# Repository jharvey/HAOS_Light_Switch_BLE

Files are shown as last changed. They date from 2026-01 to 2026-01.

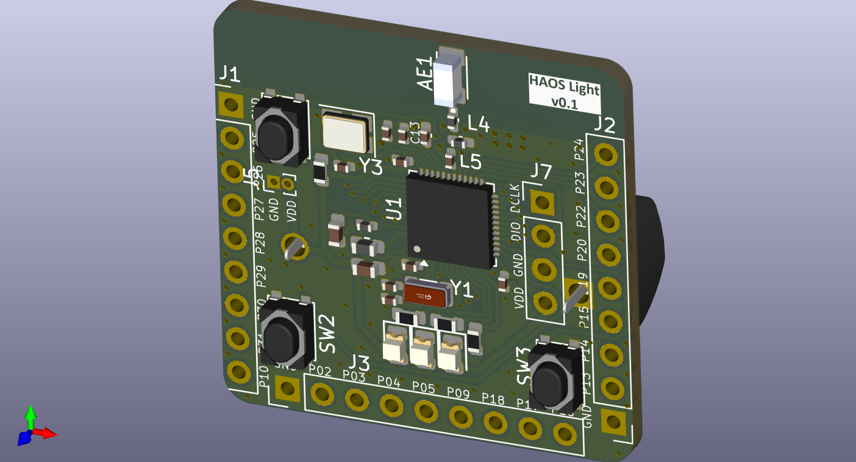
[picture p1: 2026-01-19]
pcb/HAOS_Light_Switch_BLE_KiCAD-9/jlcpcb/V0.1/HAOS_Light_Switch_BLE_ISO-front.png

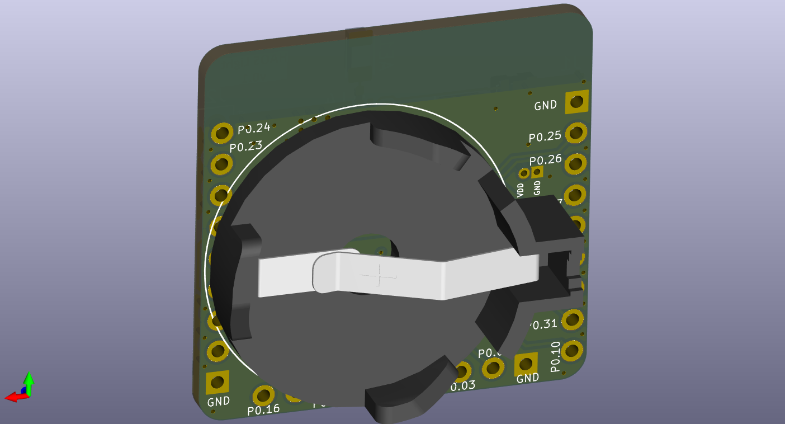
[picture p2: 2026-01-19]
pcb/HAOS_Light_Switch_BLE_KiCAD-9/jlcpcb/V0.1/HAOS_Light_Switch_BLE_ISO-back.png

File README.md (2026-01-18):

## Overview 

**Reference Designs** based on 
- Mohamed-U3 PCB V3.1 of hackaBLE https://github.com/Mohamed-U3/ElectronutLabs-hackaBLE
- Reference code https://github.com/agittins/NarfButt\
- uses https://github.com/bouni/kicad-jlcpcb-tools for JLCPCB intergration.
- uses https://raw.githubusercontent.com/CDFER/

**Features**

- Raytac MDBT42 based on Nordic Semiconductor's nRF52832 SOC with chip antenna
- 3 LED's
- Button user configurable, set as RESET by default
- SWD programming headers
- CR2032 power
- Button up
- Button down

**nRF52 IO**
- P0.00 32.768KHz with 12pF load caps
- P0.01 32.768KHz with 12pF load caps
- P0.11 Up push button
- P0.12 Down push button
- P0.17 Red LED via 33 ohm pull up at about 5ma when on. 
- P0.18 Green LED via 10 ohm pull up at about 5ma when on. 
- P0.19 White LED via 10 ohm pull up at about 5ma when on. 
- P0.21 Reset push button via 10k pull up resistor. 
- Ant 0.8pF and 3.9nH filter to PCB trace antenna. 
- XC1 ABM8-32.000MHZ-B2-T3 with 12pF load caps
- XC2 ABM8-32.000MHZ-B2-T3 with 12pF load caps
- VDD 4.7uF, 0.1uF, 0.1uF caps to gnd
- DEC1 0.1uF to Ggnd
- DEC2 No connection
- DEC3 No connection
- DEC4 to DCC via inductors listed below. 
- DCC 10uH to 15nH to DEC4 to 1uF to gnd
- SWD is connected to a dedicated connector with VDD and gnd
- All unused pins are routed to a connector which allows probing with a scope or adding prototype features.

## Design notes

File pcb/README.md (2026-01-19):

# HAOS_Light_Switch_BLE
A compact Nordic nRF52832 BLE module for HAOS light switch signals.

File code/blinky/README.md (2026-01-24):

## 1. Brief Overview
This is a baby step for making a BLE switch for HAOS. This is intended to simply blink an LED showing that you have suscessfully programmed the device. It's a hello world / baby step applicaion. 

## 2. Installation & VS Code Setup
To compile and flash this project, your development environment must be configured for **nRF Connect SDK (NCS) v3.x.x (2026)**.

### Software Prerequisites
1.  **nRF Connect Desktop:** Install the [nRF Connect Desktop tool](https://www.nordicsemi.com).
2.  **Toolchain:** Use the **Toolchain Manager** within nRF Connect Desktop to install **SDK v3.2.1** (or the latest stable 2026 release).
3.  **VS Code Extensions:**
    *   **nRF Connect for VS Code Extension Pack** (Essential).
    *   **C/C++ Extension** (by Microsoft).

### Building the Project
1.  Open the `code/HAOS_Button` folder in VS Code.
2.  In the nRF Connect Sidebar, click **Add Build Configuration**.
3.  **Board Target:** Select `nrf52dk/nrf52832`.
4.  **Configuration:** Ensure `prj.conf` is selected.
5.  Click **Build Configuration**. 
    *   *Note: Use **Pristine Build** (Refresh icon) if you modify `app.overlay` or `prj.conf`.*

## 3. Hardware Specifications & Key Assumptions
This project is mapped to the custom HAOS PCB layout.

### GPIO Mapping
The hardware utilizes the following pinout as defined in the `app.overlay`:

| Component | GPIO Pin | Logic | Description |
| :--- | :--- | :--- | :--- |
| **Red LED** | `P0.06` | Active Low | Status/Error Indicator |
| **White LED** | `P0.07` | Active Low | Secondary Indicator |
| **Green LED** | `P0.08` | Active Low | Success/Heartbeat Indicator |
| **Up Button** | `P0.11` | Pull-Up | Shorts to GND when pressed |
| **Down Button** | `P0.12` | Pull-Up | Shorts to GND when pressed |
| **Reset/Button**| `P0.21` | Pull-Up | Hardware Reset / Input |

### Oscillator & Crystal Frequencies
To maintain BLE timing accuracy and achieve micro-ampere sleep currents, the following crystal assumptions are made:
*   **High-Frequency Clock (HFCLK):** 32 MHz Crystal (Required for BLE radio operation).
*   **Low-Frequency Clock (LFCLK):** 32.768 kHz Crystal (Required for accurate sleep-interval timing).
*   **DCDC Converter:** Enabled in `prj.conf` to reduce peak current draw from the CR2032 during radio bursts.

### Programming Interface (J6 Header)
*   **Connector:** Tag-Connect TC2030-IDC-NL (6-pin).
*   **Programmer:** SEGGER J-Link (e.g., EDU Mini).
*   **Power Note:** The programmer does **not** provide power via the J6 header. The board must be powered by the CR2032 or an external 3V supply during flashing.

## 4. Debugging & Output
Debugging is handled via **SWO (Single Wire Output)** on the J6 header to avoid the power overhead of a traditional UART.
*   **Frequency:** 2,000,000 Hz.
*   **Tools:** View logs using the **SEGGER J-Link SWO Viewer**.

### Notes
2026-01-24 As of this date, the baord has not be manufactured or tested. This is still a draft version.

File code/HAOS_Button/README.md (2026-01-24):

# HAOS Button: Ultra-Low Power BLE Light Switch

An ultra-low-power, CR2032-battery-operated Bluetooth Low Energy (BLE) light switch designed specifically for **Home Assistant**. This project utilizes the **BTHome V2** protocol to provide long battery life and "no-pairing" automatic discovery.

## 1. Brief Overview
The HAOS Button is a custom-engineered remote for Home Assistant. Instead of maintaining a power-hungry active connection, it utilizes BLE Advertising to broadcast state changes.
*   **Hardware:** nRF52832 SoC.
*   **Power:** Powered by a single **CR2032 coin cell**.
*   **Protocol:** BTHome V2 (non-encrypted) for instant integration with HAOS.
*   **Form Factor:** Designed to fit behind existing wall plates or as a standalone remote. Small enough to be on a key chain. 

## 2. Installation & VS Code Setup
To compile and flash this project, your development environment must be configured for **nRF Connect SDK (NCS) v3.x.x (2026)**.

### Software Prerequisites
1.  **nRF Connect Desktop:** Install the [nRF Connect Desktop tool](https://www.nordicsemi.com).
2.  **Toolchain:** Use the **Toolchain Manager** within nRF Connect Desktop to install **SDK v3.2.1** (or the latest stable 2026 release).
3.  **VS Code Extensions:**
    *   **nRF Connect for VS Code Extension Pack** (Essential).
    *   **C/C++ Extension** (by Microsoft).

### Building the Project
1.  Open the `code/HAOS_Button` folder in VS Code.
2.  In the nRF Connect Sidebar, click **Add Build Configuration**.
3.  **Board Target:** Select `nrf52dk/nrf52832`.
4.  **Configuration:** Ensure `prj.conf` is selected.
5.  Click **Build Configuration**. 
    *   *Note: Use **Pristine Build** (Refresh icon) if you modify `app.overlay` or `prj.conf`.*

## 3. Hardware Specifications & Key Assumptions
This project is mapped to the custom HAOS PCB layout.

### GPIO Mapping
The hardware utilizes the following pinout as defined in the `app.overlay`:

| Component | GPIO Pin | Logic | Description |
| :--- | :--- | :--- | :--- |
| **Red LED** | `P0.06` | Active Low | Status/Error Indicator |
| **White LED** | `P0.07` | Active Low | Secondary Indicator |
| **Green LED** | `P0.08` | Active Low | Success/Heartbeat Indicator |
| **Up Button** | `P0.11` | Pull-Up | Shorts to GND when pressed |
| **Down Button** | `P0.12` | Pull-Up | Shorts to GND when pressed |
| **Reset/Button**| `P0.21` | Pull-Up | Hardware Reset / Input |

### Oscillator & Crystal Frequencies
To maintain BLE timing accuracy and achieve micro-ampere sleep currents, the following crystal assumptions are made:
*   **High-Frequency Clock (HFCLK):** 32 MHz Crystal (Required for BLE radio operation).
*   **Low-Frequency Clock (LFCLK):** 32.768 kHz Crystal (Required for accurate sleep-interval timing).
*   **DCDC Converter:** Enabled in `prj.conf` to reduce peak current draw from the CR2032 during radio bursts.

### Programming Interface (J6 Header)
*   **Connector:** Tag-Connect TC2030-IDC-NL (6-pin).
*   **Programmer:** SEGGER J-Link (e.g., EDU Mini).
*   **Power Note:** The programmer does **not** provide power via the J6 header. The board must be powered by the CR2032 or an external 3V supply during flashing.

## 4. Debugging & Output
Debugging is handled via **SWO (Single Wire Output)** on the J6 header to avoid the power overhead of a traditional UART.
*   **Frequency:** 2,000,000 Hz.
*   **Tools:** View logs using the **SEGGER J-Link SWO Viewer**.

## 5. Home Assistant Integration
1.  Navigate to **Settings > Devices & Services** in your HAOS instance.
2.  Press any button on the device to begin advertising.
3.  Home Assistant will automatically discover the device as a **BTHome** integration.
4.  Once configured, buttons will appear as event entities for use in Automations.

### Notes
2026-01-24 As of this date, the baord has not be manufactured or tested. This is still a draft version.

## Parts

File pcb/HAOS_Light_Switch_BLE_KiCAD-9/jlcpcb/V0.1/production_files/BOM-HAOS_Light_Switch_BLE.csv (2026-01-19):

Comment | Designator | Footprint | LCSC | Quantity
100nF | C11,C7,C9 | C_0402 | C307331 | 3
100pF | C12 | C_0402 | C1546 | 1
10kΩ | R1 | R_0603 | C25804 | 1
10uH,3mA | L2 | L_0603 | C1035 | 1
10Ω | R2,R3 | R_0603 | C22859 | 2
12pF | C1,C2,C5,C6 | C_0402 | C1547 | 4
15nH,300mA | L1 | L_0402 | C27143 | 1
1pF | C3 | C_0402 | C1550 | 1
1uF | C10 | C_0603 | C15849 | 1
2.7uH | L5 | L_0402_1005Metric_Pad0.77x0.64mm_HandSolder | C91239 | 1
3.9uH | L4 | L_0402_1005Metric_Pad0.77x0.64mm_HandSolder | C98062 | 1
33Ω | R4 | R_0603 | C23140 | 1
4.7uF | C8 | C_0603 | C19666 | 1
47uF | C4 | C_0805 | C124129 | 1
ABM8-32.000MHZ-B2-T3 | Y3 | Crystal_SMD_Abracon_ABM8AIG-4Pin_3.2x2.5mm | C1986513 | 1
Battery_CR2032 | J4 | BatteryHolder_MYOUNG_BS-07-A1BJ001_CR2032 | C2979167 | 1
Green | D2 | D_0805 | C2297 | 1
Q13FC1350000400 | Y1 | FC-135R_L3.2-W1.5 | C32346 | 1
Red | D3 | D_0805 | C84256 | 1
SW_Push | SW1,SW2,SW3 | SW_SPST_PTS810 | C2888429 | 3
White | D1 | D_0805 | C34499 | 1
nrf52832 | U1 | QFN-48-1EP_6x6mm_P0.4mm_EP4.4x4.4mm_ThermalVias | C77540 | 1
2450AT18A100E | AE1 | ANTC3216X140N |  | 1

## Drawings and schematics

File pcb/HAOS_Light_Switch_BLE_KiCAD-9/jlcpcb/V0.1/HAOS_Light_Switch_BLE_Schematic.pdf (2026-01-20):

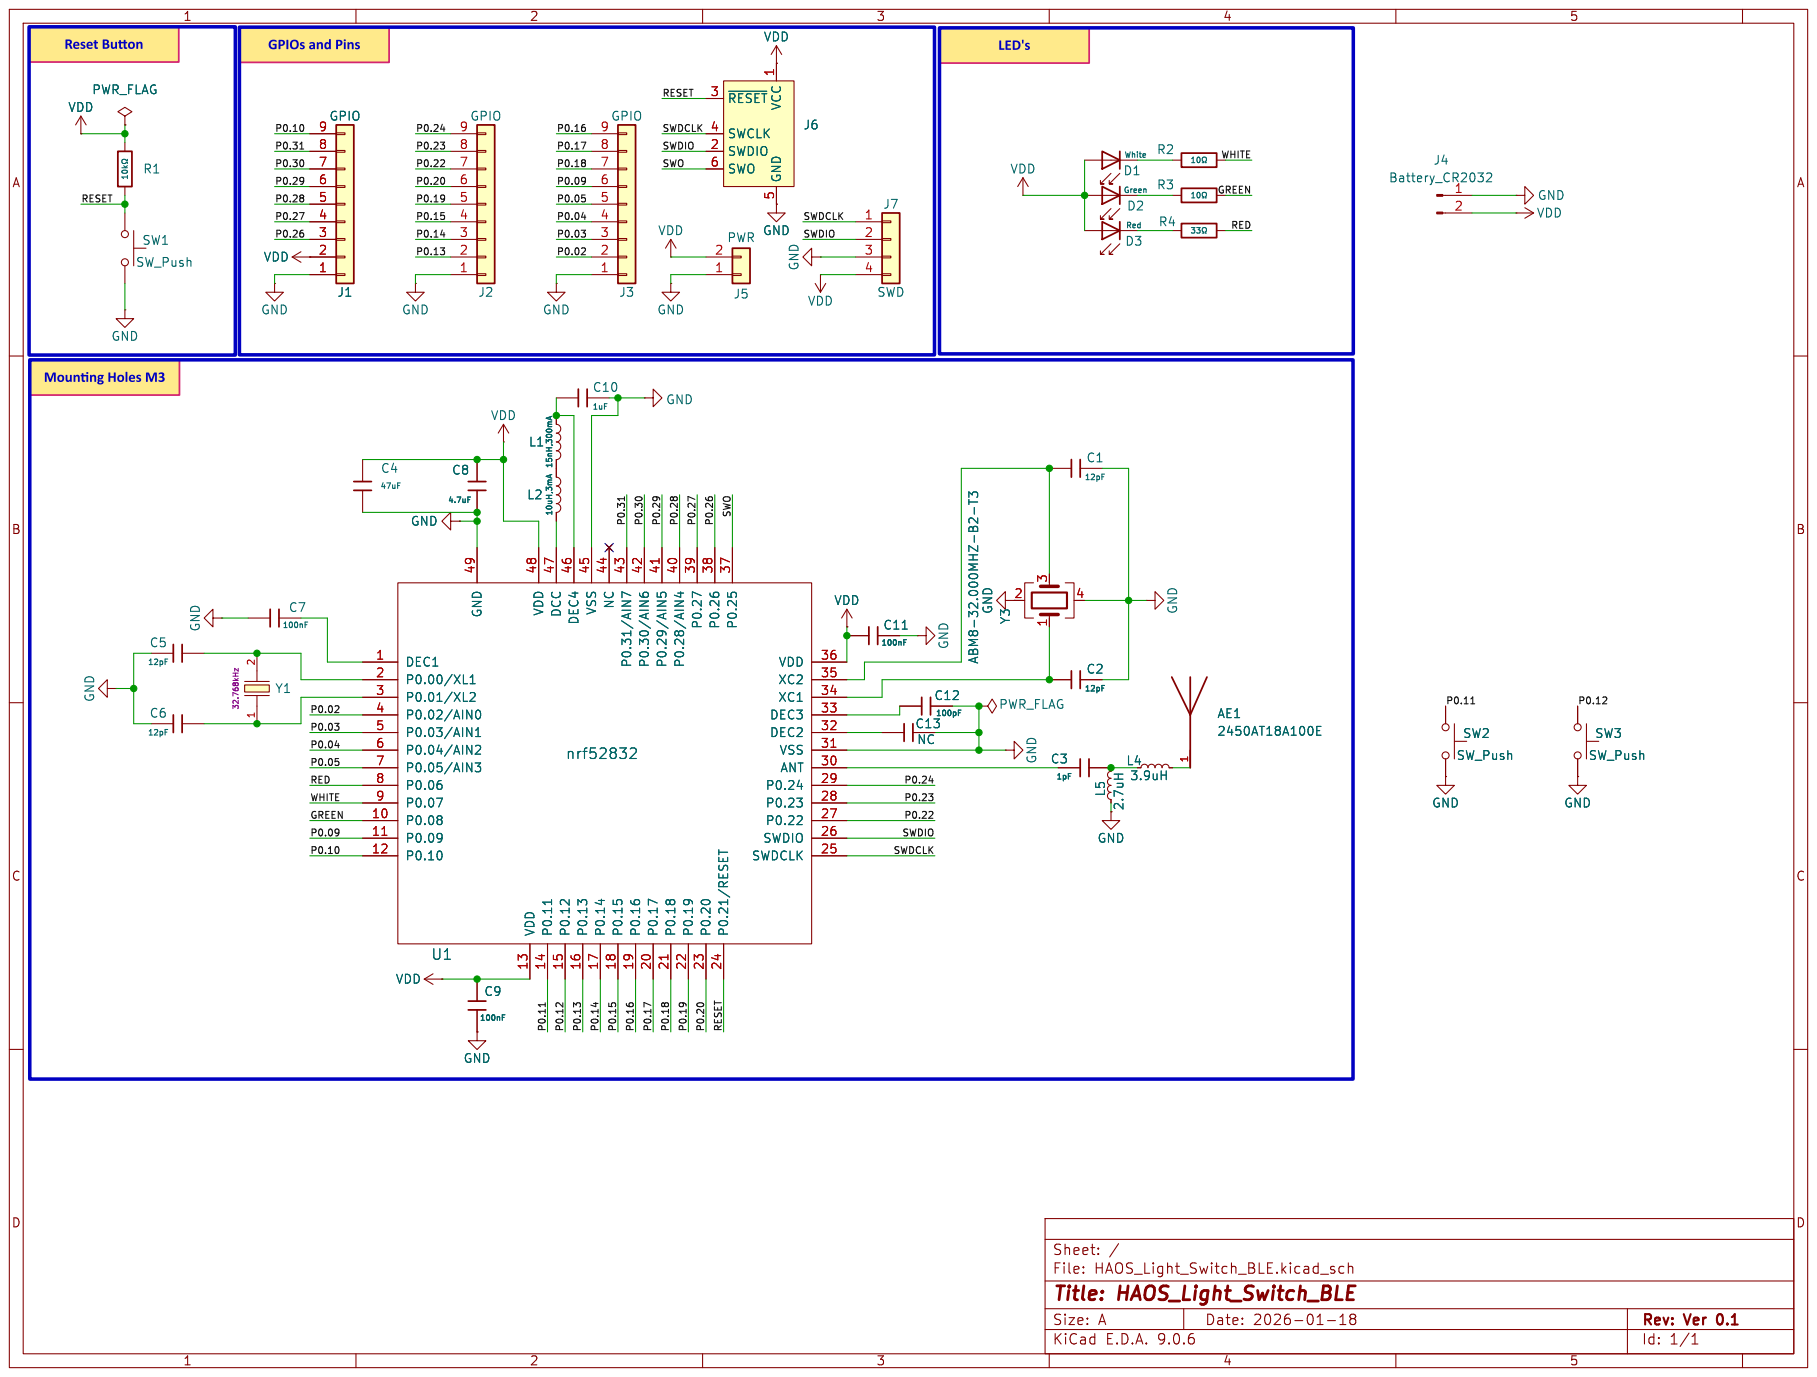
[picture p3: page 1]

5 ~{RESET} 3 SWCLK 4 SWDIO 2 SWO 6

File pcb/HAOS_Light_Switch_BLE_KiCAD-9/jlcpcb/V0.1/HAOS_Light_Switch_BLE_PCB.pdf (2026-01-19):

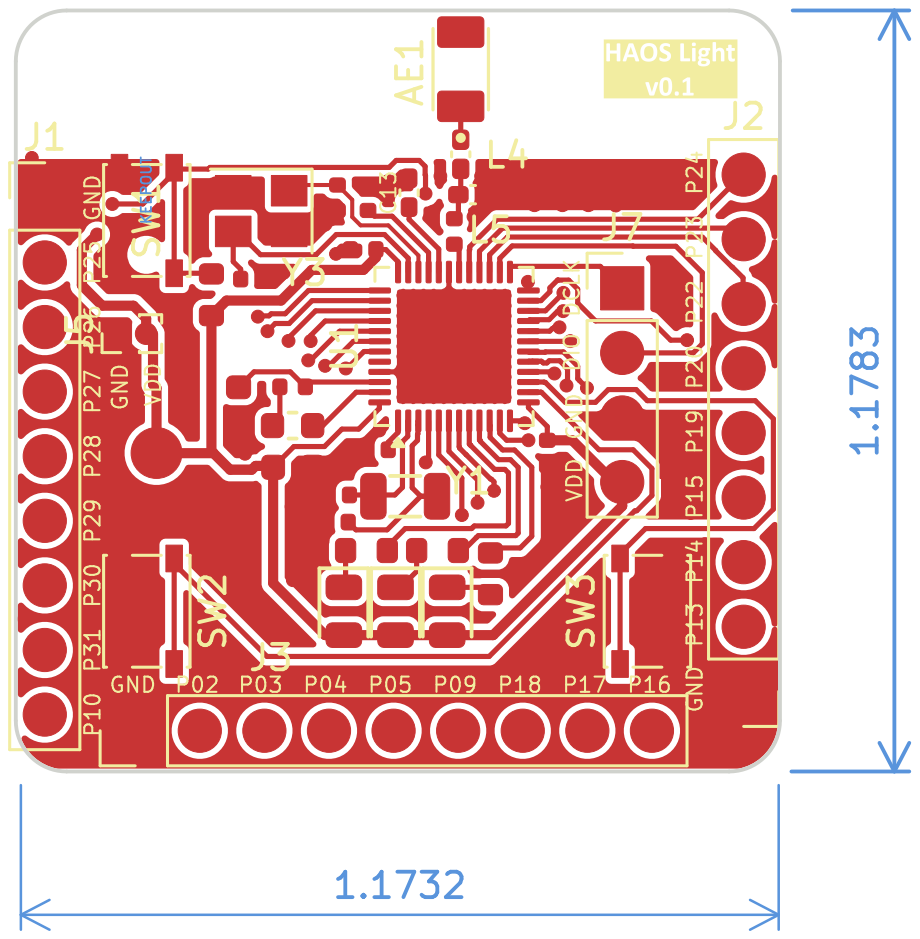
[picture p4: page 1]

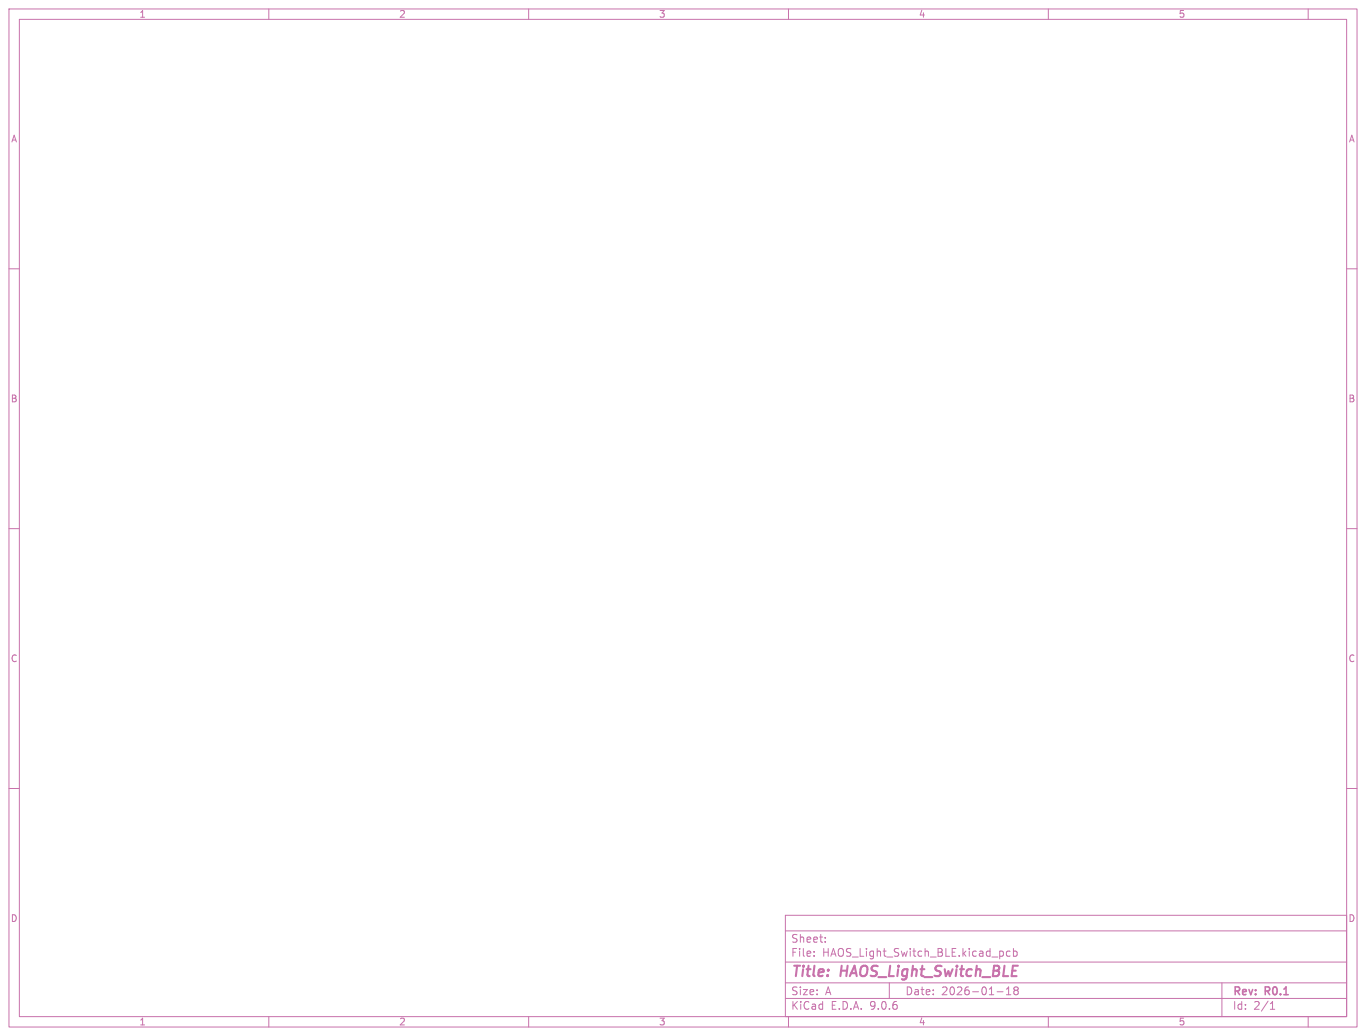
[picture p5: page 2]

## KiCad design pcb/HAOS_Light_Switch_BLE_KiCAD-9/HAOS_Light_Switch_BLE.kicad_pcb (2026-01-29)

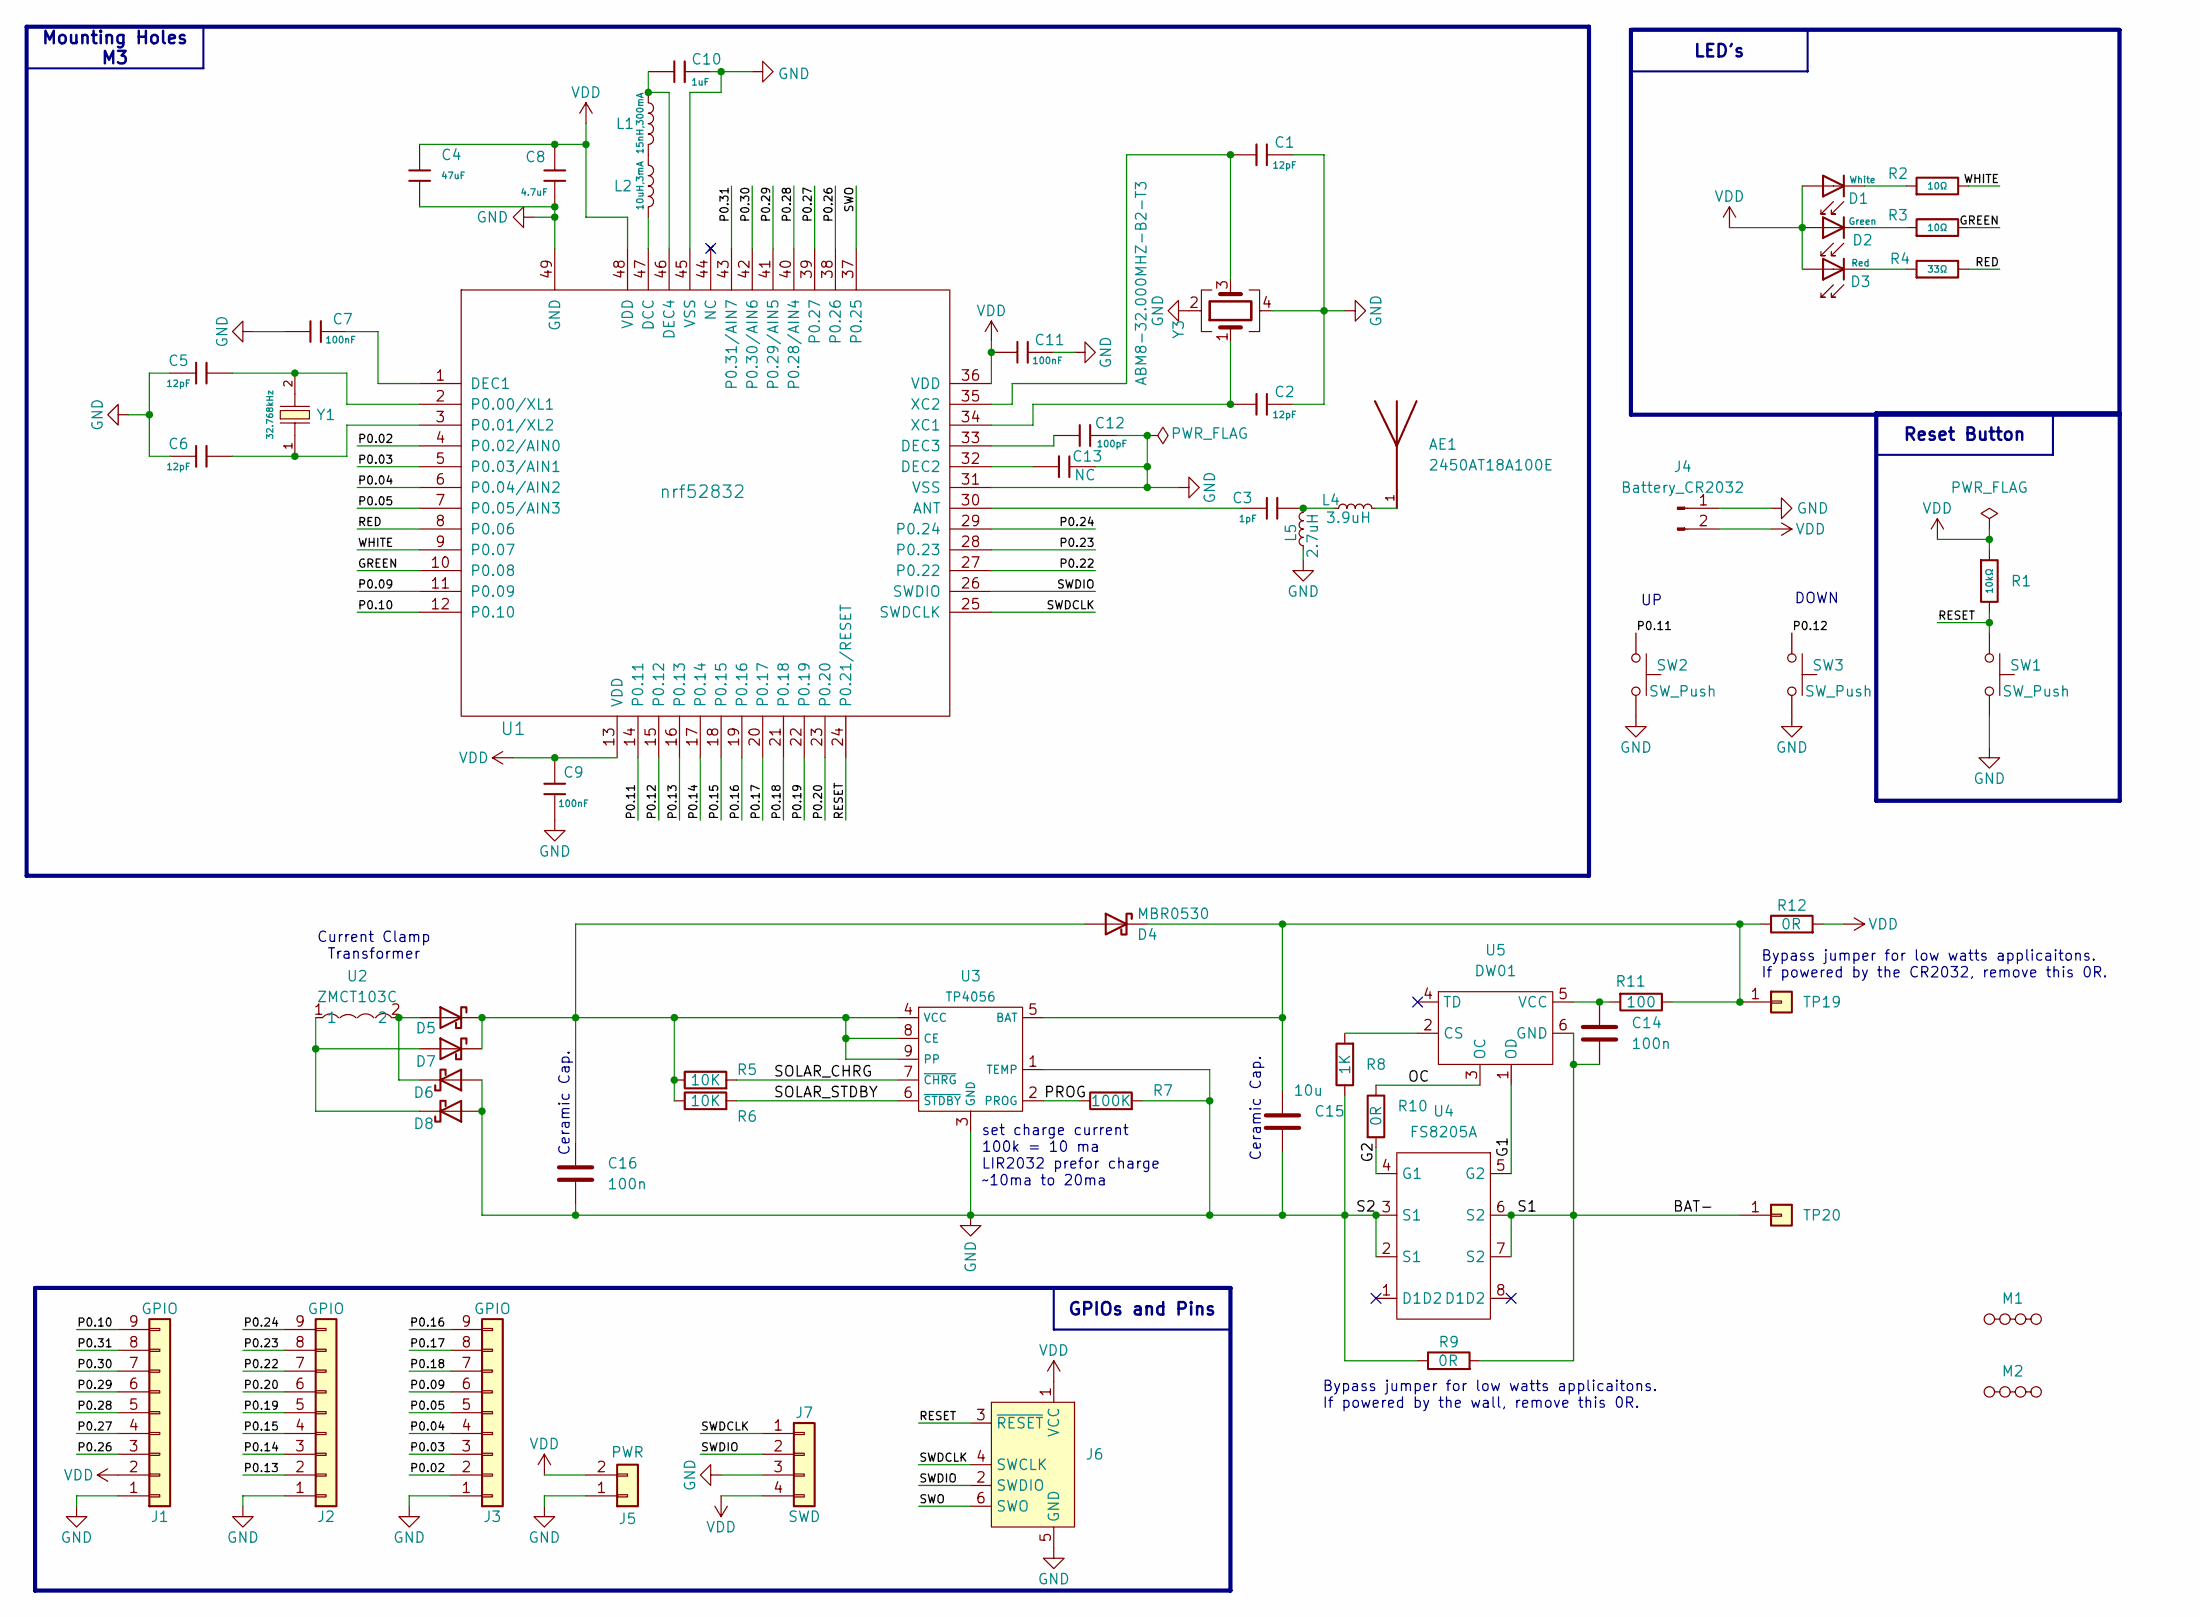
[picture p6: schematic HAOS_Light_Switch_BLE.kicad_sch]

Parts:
AE1: 2450AT18A100E; ANTC3216X140N; PARTREV 1.3
C1, C2, C5, C6: 12pF; C_0402; Voltage Rated 50V; Tolerance ±5%; Part 0402CG120J500NT; LCSC C1547
C3: 1pF; C_0402; Voltage Rated 50V; LCSC C1550
C4: 47uF; C_0805; LCSC C124129
C7, C9, C11: 100nF; C_0402; Voltage Rated 50V; Tolerance ±10%; Part CL05B104KB54PNC; LCSC C307331
C8: 4.7uF; C_0603; Voltage Rated 16V; Tolerance ±10%; Part CL10A475KO8NNNC; LCSC C19666
C10: 1uF; C_0603; Voltage Rated 50V; Tolerance ±10%; Part CL10A105KB8NNNC; LCSC C15849
C12: 100pF; C_0402; Voltage Rated 50V; Tolerance ±5%; Part 0402CG101J500NT; LCSC C1546
C13: NC; C_0402_1005Metric_Pad0.74x0.62mm_HandSolder
C14, C16: 100n; C_0603_1608Metric; LCSC C14663
C15: 10u; C_0603_1608Metric; LCSC C194427
D1: White; D_0805; Part KT-0805W; LCSC C34499
D2: Green; D_0805; Part KT-0805G; LCSC C2297
D3: Red; D_0805; Forward Voltage (VF) 1.6V~2.6V; Part NCD0805R1; LCSC C84256
D4, D5, D6, D7, D8: MBR0530; D_SOD-123; LCSC C77336
J1, J2, J3: GPIO; PinHeader_1x09_P2.54mm_Vertical
J4: Battery_CR2032; BatteryHolder_MYOUNG_BS-07-A1BJ001_CR2032; LCSC C2979167
J5: PWR; PinHeader_1x02_P1.00mm_Vertical
J6: Conn_ARM_SWD_TagConnect_TC2030-NL; Tag-Connect_TC2030-IDC-NL_2x03_P1.27mm_Vertical
J7: SWD; PinHeader_1x04_P2.54mm_Vertical
L1: 15nH,300mA; L_0402; Tolerance ±5%; Part SDCL1005C15NJTDF; LCSC C27143
L2: 10uH,3mA; L_0603; Tolerance ±10%; Part SDFL1608S100KTF; LCSC C1035
L4: 3.9uH; L_0402_1005Metric_Pad0.77x0.64mm_HandSolder; LCSC C98062
L5: 2.7uH; L_0402_1005Metric_Pad0.77x0.64mm_HandSolder; LCSC C91239
M1, M2: MouseBites, Cosmetic, JLCPCB, 1.6mm
R1: 10kΩ; R_0603; Overload Voltage (Max) 75V; Tolerance ±1%; Part 0603WAF1002T5E; LCSC C25804
R2, R3: 10Ω; R_0603; Overload Voltage (Max) 75V; Tolerance ±1%; Part 0603WAF100JT5E; LCSC C22859
R4: 33Ω; R_0603; Overload Voltage (Max) 75V; Tolerance ±1%; Part 0603WAF330JT5E; LCSC C23140
R5, R6: 10K; R_0603_1608Metric; LCSC C25804
R7: 100K; R_0603_1608Metric; LCSC C25803
R8: 1K; R_0603_1608Metric; LCSC C21190
R9, R10, R12: 0R; R_0603_1608Metric; LCSC C21189
R11: 100; R_0603_1608Metric; LCSC C4184
SW1, SW2, SW3: SW_Push; SW_SPST_PTS810; LCSC C2888429
TP19, TP20: CONN_01; PinHeader_1x01_P1.00mm_Vertical; LCSC DNP
U1: nrf52832; QFN-48-1EP_6x6mm_P0.4mm_EP4.4x4.4mm_ThermalVias; LCSC C77540
U2: ZMCT103C; XFMR-TH_ZMCT103C; LCSC Part C94571
U3: TP4056; ESOP-8_L4.9-W3.9-P1.27-LS6.0-BL-EP; LCSC C16581
U4: FS8205A; TSSOP-8_L4.4-W3.0-P0.65-LS6.4-BL-2; LCSC C16052
U5: DW01; SOT-23-6_L2.9-W1.6-P0.95-LS2.8-BL; LCSC C351410
Y1: Q13FC1350000400; FC-135R_L3.2-W1.5; Frequency Tolerance ±20ppm; Part Q13FC13500004; LCSC C32346
Y3: ABM8-32.000MHZ-B2-T3; Crystal_SMD_Abracon_ABM8AIG-4Pin_3.2x2.5mm; PARTREV 44041; LCSC C1986513

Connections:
/BAT-: C14.2, R9.2, TP20.1, U4.6 (S2), U4.7 (S2), U5.6 (GND)
/G1: U4.5 (G2), U5.1 (OD)
/G2: R10.2, U4.4 (G1)
/GREEN: R3.2, U1.10 (P0.08)
/OC: R10.1, U5.3 (OC)
/P0.02: J3.2, U1.4 (P0.02/AIN0)
/P0.03: J3.3, U1.5 (P0.03/AIN1)
/P0.04: J3.4, U1.6 (P0.04/AIN2)
/P0.05: J3.5, U1.7 (P0.05/AIN3)
/P0.09: J3.6, U1.11 (P0.09)
/P0.10: J1.9, U1.12 (P0.10)
/P0.11: SW2.1, U1.14 (P0.11)
/P0.12: SW3.1, U1.15 (P0.12)
/P0.13: J2.2, U1.16 (P0.13)
/P0.14: J2.3, U1.17 (P0.14)
/P0.15: J2.4, U1.18 (P0.15)
/P0.16: J3.9, U1.19 (P0.16)
/P0.17: J3.8, U1.20 (P0.17)
/P0.18: J3.7, U1.21 (P0.18)
/P0.19: J2.5, U1.22 (P0.19)
/P0.20: J2.6, U1.23 (P0.20)
/P0.22: J2.7, U1.27 (P0.22)
/P0.23: J2.8, U1.28 (P0.23)
/P0.24: J2.9, U1.29 (P0.24)
/P0.26: J1.3, U1.38 (P0.26)
/P0.27: J1.4, U1.39 (P0.27)
/P0.28: J1.5, U1.40 (P0.28/AIN4)
/P0.29: J1.6, U1.41 (P0.29/AIN5)
/P0.30: J1.7, U1.42 (P0.30/AIN6)
/P0.31: J1.8, U1.43 (P0.31/AIN7)
/PROG: R7.1, U3.2 (PROG)
/RED: R4.2, U1.8 (P0.06)
/RESET: J6.3 (~RESET), R1.2, SW1.1, U1.24 (P0.21/RESET)
/SOLAR_CHRG: R5.2, U3.7 (~CHRG)
/SOLAR_STDBY: R6.2, U3.6 (~STDBY)
/SWDCLK: J6.4 (SWCLK), J7.1, U1.25 (SWDCLK)
/SWDIO: J6.2 (SWDIO), J7.2, U1.26 (SWDIO)
/SWO: J6.6 (SWO), U1.37 (P0.25)
/WHITE: R2.2, U1.9 (P0.07)
GND: C1.1, C2.1, C4.2, C5.1, C6.1, C7.1, C8.1, C9.1, C10.2, C11.2, C12.2, C13.1, C15.2, C16.2, D7.2 (A), D8.2 (A), J1.1, J2.1, J3.1, J4.1, J5.1, J6.5 (GND), J7.3, L5.1, R7.2, R8.1, R9.1, SW1.2, SW2.2, SW3.2, U1.31 (VSS), U1.45 (VSS), U1.49 (GND), U3.1 (TEMP), U3.3 (GND), U4.2 (S1), U4.3 (S1), Y3.2, Y3.4
unnamed: AE1.1, L4.2
unnamed: C3.2, L4.1, L5.2
unnamed: D1.1, R2.1
unnamed: D2.1, R3.1
unnamed: D3.1, R4.1
unnamed: C16.1, D4.2 (A), D5.1 (K), D6.1 (K), R5.1, R6.1, U3.4 (VCC), U3.8 (CE), U3.9 (PP)
unnamed: C15.1, D4.1 (K), R11.1, R12.1, TP19.1, U3.5 (BAT)
unnamed: D5.2 (A), D7.1 (K), U2.2
unnamed: D6.2 (A), D8.1 (K), U2.1
unnamed: L1.2, L2.1
unnamed: C3.1, U1.30 (ANT)
unnamed: L2.2, U1.47 (DCC)
unnamed: C7.2, U1.1 (DEC1)
unnamed: C13.2, U1.32 (DEC2)
unnamed: C12.1, U1.33 (DEC3)
unnamed: C10.1, L1.1, U1.46 (DEC4)
unnamed: C5.2, U1.2 (P0.00/XL1), Y1.2
unnamed: C6.2, U1.3 (P0.01/XL2), Y1.1
unnamed: C2.2, U1.34 (XC1), Y3.1
unnamed: C1.2, U1.35 (XC2), Y3.3
unnamed: R8.2, U5.2 (CS)
unnamed: C14.1, R11.2, U5.5 (VCC)
VDD: C4.1, C8.2, C9.2, C11.1, D1.2, D2.2, D3.2, J1.2, J4.2, J5.2, J6.1 (VCC), J7.4, R1.1, R12.2, U1.13 (VDD), U1.36 (VDD), U1.48 (VDD)

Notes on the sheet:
set charge current 100k = 10 ma LIR2032 prefor charge ~10ma to 20ma
Ceramic Cap.
Bypass jumper for low watts applicaitons. If powered by the wall, remove this 0R.
Bypass jumper for low watts applicaitons. If powered by the CR2032, remove this 0R.
DOWN
Current Clamp Transformer
LED's
GPIOs and Pins
Reset Button
Mounting Holes M3

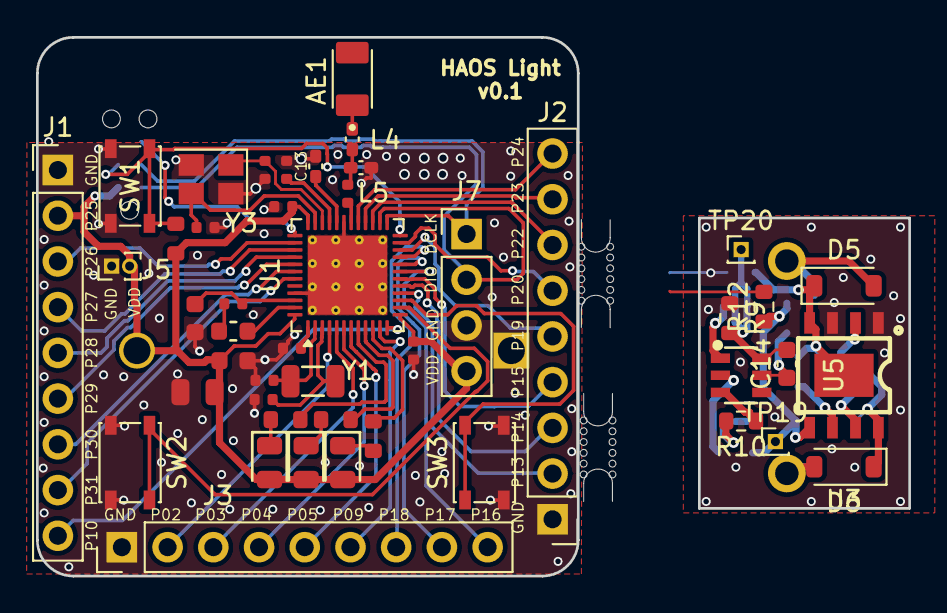
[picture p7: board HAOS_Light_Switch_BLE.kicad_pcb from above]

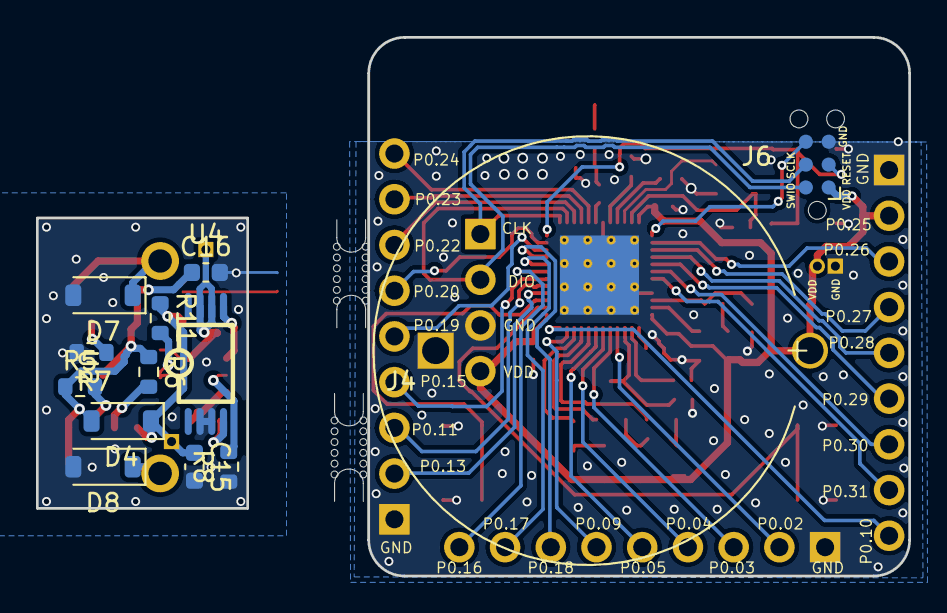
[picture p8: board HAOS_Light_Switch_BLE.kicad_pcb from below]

Board: 2 copper layers, 48.5 x 29.9 mm, 62 parts (14 on the bottom side), 63 nets.

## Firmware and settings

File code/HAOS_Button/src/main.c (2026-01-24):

#include <zephyr/kernel.h>
#include <zephyr/drivers/gpio.h>
#include <zephyr/logging/log.h>
#include <zephyr/bluetooth/bluetooth.h>

LOG_MODULE_REGISTER(haos_app, LOG_LEVEL_INF);

static const struct gpio_dt_spec led = GPIO_DT_SPEC_GET(DT_ALIAS(led0), gpios);
static const struct gpio_dt_spec btn_up = GPIO_DT_SPEC_GET(DT_ALIAS(sw0), gpios);
static const struct gpio_dt_spec btn_dn = GPIO_DT_SPEC_GET(DT_ALIAS(sw1), gpios);

/* Sends BTHome v2 packet for button events (Object ID 0x3A) */
void send_bthome_event(uint8_t event_id) {
    static uint8_t packet_id = 0;
    
    struct bt_data ad[] = {
        BT_DATA_BYTES(BT_DATA_FLAGS, BT_LE_AD_GENERAL | BT_LE_AD_NO_BREDR),
        BT_DATA_BYTES(BT_DATA_UUID16_ALL, 0xD2, 0xFC), // BTHome Service UUID
        BT_DATA_BYTES(BT_DATA_SVC_DATA16, 
            0xD2, 0xFC, 
            0x40,       // Device Info: No encryption, V2
            0x3A,       // Object ID: Button event
            event_id    // Value: 0x01 (Press) or 0x02 (Double/Down example)
        )
    };

    bt_le_adv_start(BT_LE_ADV_NCONN, ad, ARRAY_SIZE(ad), NULL, 0);
    k_msleep(150); // Broadcast for 150ms to ensure HAOS hears it
    bt_le_adv_stop();
    LOG_INF("BLE Event 0x%02X sent (Packet %d)", event_id, ++packet_id);
}

int main(void) {
    if (!gpio_is_ready_dt(&led) || !gpio_is_ready_dt(&btn_up) || !gpio_is_ready_dt(&btn_dn)) {
        LOG_ERR("Hardware not ready");
        return 0;
    }

    gpio_pin_configure_dt(&led, GPIO_OUTPUT_ACTIVE);
    gpio_pin_configure_dt(&btn_up, GPIO_INPUT);
    gpio_pin_configure_dt(&btn_dn, GPIO_INPUT);

    if (bt_enable(NULL)) {
        LOG_ERR("Bluetooth failed");
        return 0;
    }

    LOG_INF("Dual Button Switch Ready - P0.11 (Up), P0.12 (Down)");

    while (1) {
        // Toggle LED to show system heartbeat
        gpio_pin_toggle_dt(&led);

        // Check Up Button (P0.11)
        if (gpio_pin_get_dt(&btn_up) == 1) {
            LOG_INF("UP Pressed");
            send_bthome_event(0x01); // Standard "Press"
            while(gpio_pin_get_dt(&btn_up) == 1) k_msleep(10); // Simple debounce
        }

        // Check Down Button (P0.12)
        if (gpio_pin_get_dt(&btn_dn) == 1) {
            LOG_INF("DOWN Pressed");
            send_bthome_event(0x02); // Sending 0x02 to distinguish from Up
            while(gpio_pin_get_dt(&btn_dn) == 1) k_msleep(10); // Simple debounce
        }

        k_msleep(250); // General polling interval
    }
}

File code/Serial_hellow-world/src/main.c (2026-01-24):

#include <zephyr/logging/log.h>

// Register the log module for this file
LOG_MODULE_REGISTER(my_app, LOG_LEVEL_INF);

int main(void) {
    // ... your existing LED setup code ...

    while (1) {
        LOG_INF("Hello World");
        // ... your existing LED blink code ...
        k_msleep(1000);
    }
}

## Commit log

2026-01-18 Revise LED specifications and integration links
    Updated LED descriptions and integration references in README.
2026-01-19 Initial PCB commit.
    [HAOS_Light_Switch_BLE.kicad_pcb, HAOS_Light_Switch_BLE.kicad_sch]
2026-01-19 Updated antenna
    [HAOS_Light_Switch_BLE.kicad_pcb, HAOS_Light_Switch_BLE.kicad_sch]
2026-01-19 updated per DRC
    [HAOS_Light_Switch_BLE.kicad_pcb]
2026-01-19 Potential 1st spin.
    [HAOS_Light_Switch_BLE.kicad_pcb, HAOS_Light_Switch_BLE.kicad_sch]
2026-01-19 Added more documentation.
    [BOM-HAOS_Light_Switch_BLE.csv, HAOS_Light_Switch_BLE.kicad_pcb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]
2026-01-19 added Tag-Connect programming connector
    [BOM-HAOS_Light_Switch_BLE.csv, HAOS_Light_Switch_BLE.kicad_pcb, HAOS_Light_Switch_BLE.kicad_sch]
2026-01-19 Added C4 to help mitigate brown out potential during radio transmissions.
    [BOM-HAOS_Light_Switch_BLE.csv, HAOS_Light_Switch_BLE.kicad_pcb, HAOS_Light_Switch_BLE.kicad_sch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]
2026-01-20 Added SWO to Tag-Connect
    [HAOS_Light_Switch_BLE.kicad_pcb, HAOS_Light_Switch_BLE.kicad_sch]
2026-01-25 added neutral current clamp draft copy of schematic.
    [HAOS_Light_Switch_BLE.kicad_sch]
2026-01-27 Draft AC power sniffer
    [HAOS_Light_Switch_BLE.kicad_pcb, HAOS_Light_Switch_BLE.kicad_sch]
2026-01-28 Draft updated trace width
    [HAOS_Light_Switch_BLE.kicad_pcb]
2026-01-29 Change R7 limiting charge current to 10ma for LIR2032 charging.
    [HAOS_Light_Switch_BLE.kicad_pcb, HAOS_Light_Switch_BLE.kicad_sch]
